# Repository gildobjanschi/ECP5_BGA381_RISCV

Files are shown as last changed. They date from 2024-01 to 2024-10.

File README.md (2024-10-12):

# Blue Whale Hardware
ECP5 FPGA board for developing a RISCV processor.

## Software
The ECP5 FPGA board was developed to enable the development of a RISCV processor and allow for for an extension connector. See the [RISCV_PROCESSOR](https://github.com/gildobjanschi/RISCV_PROCESSOR) project for detailed explanation of the Verilog code developed for this board.

## Project Status
The HW has been fully verified as part of the [RISCV_PROCESSOR](https://github.com/gildobjanschi/RISCV_PROCESSOR) project. An [extension board](https://github.com/gildobjanschi/ECP5_BGA381_RISCV_EXT)  was developed to test the extension interface. 

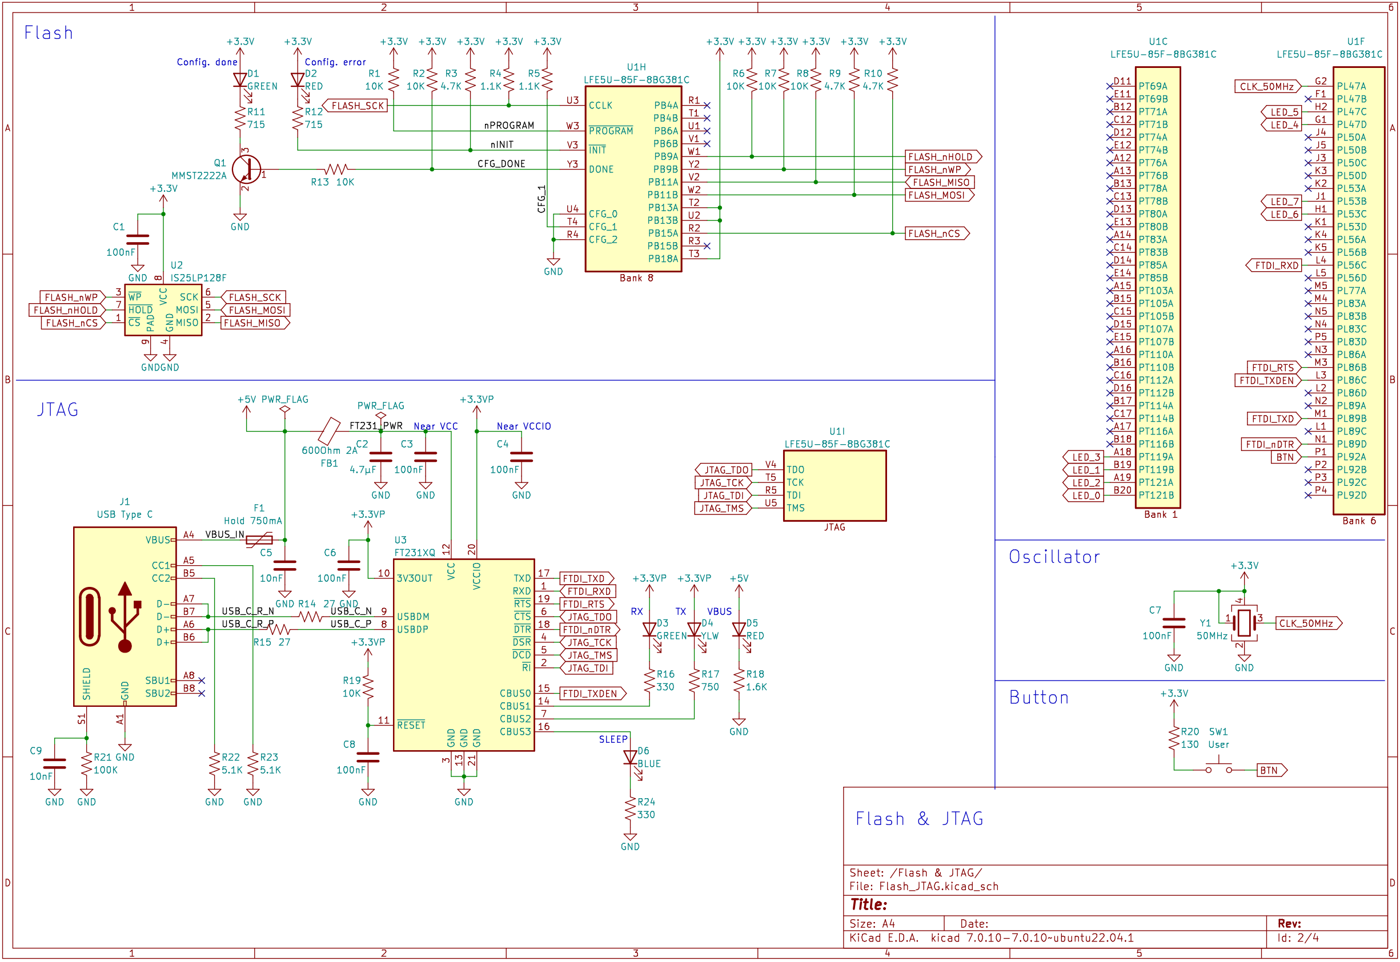
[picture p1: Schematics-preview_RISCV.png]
[](https://ECP5_BGA381_RISCV/blob/main/ECP5_board.pdf)

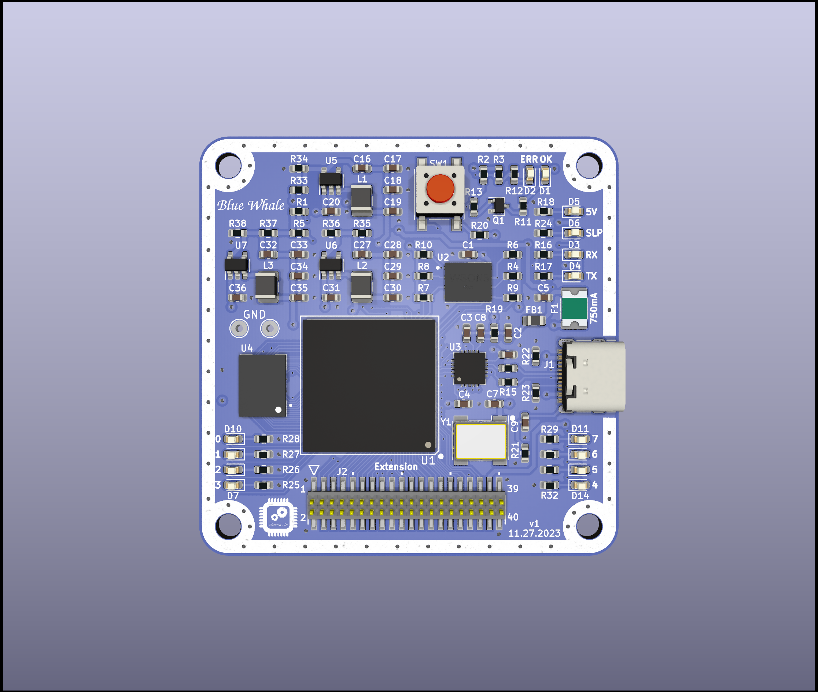
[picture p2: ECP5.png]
Blue Whale 3D view


## How To setup KiCAD
Checkout the KiCAD project and open it. In the Configure Paths dialog add: Name: ECP5_BGA381_RISCV and Path: "The full path to the GitHub directory"/GitHub/ECP5_BGA381_RISCV

In the Manage Symbol Libraries click the Project Specific Libraries tab and add: Name: ECP5_BGA381_RISCV and Library Path: ${ECP5_BGA381_RISCV}/symbols/Symbols.kicad_sym

In the Manage Footprint Libraries click the Project Specific Libraries tab and add: Name: ECP5_BGA381_RISCV and Library Path: ${ECP5_BGA381_RISCV}/footprints/Footprints.pretty

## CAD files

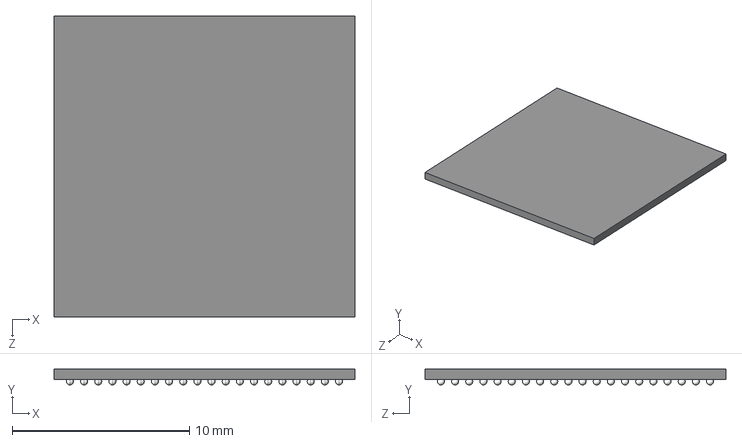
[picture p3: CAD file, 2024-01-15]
3dmodels/LFE5UM-85F-8BG381C.STEP
17.0 x 0.9 x 17.0 mm

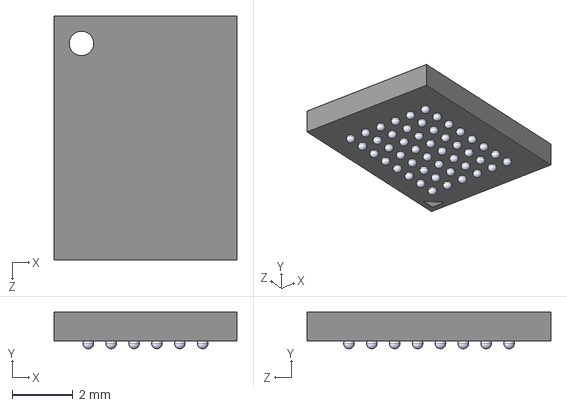
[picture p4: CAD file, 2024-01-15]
3dmodels/IS66WVE4M16EBLL-70BLI.STEP
6.00 x 1.20 x 8.00 mm

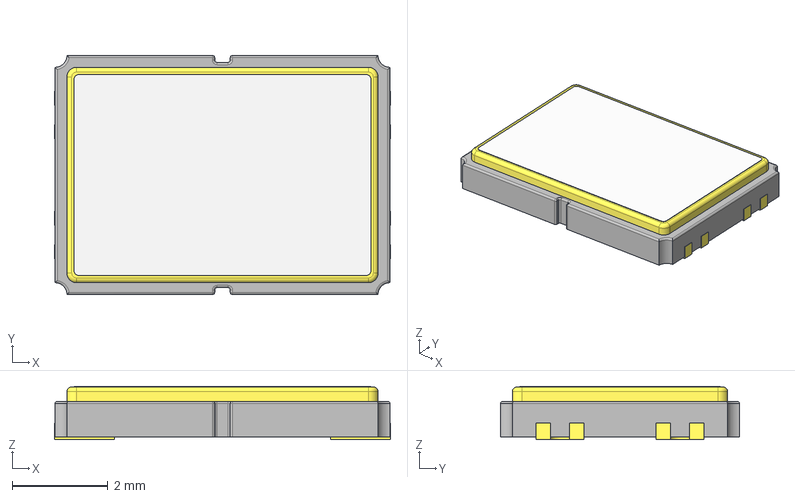
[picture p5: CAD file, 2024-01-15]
3dmodels/CRYSTAL_7050-4.step
7.02 x 5.00 x 1.11 mm
Pin
Pin001
Pin002
Pin003

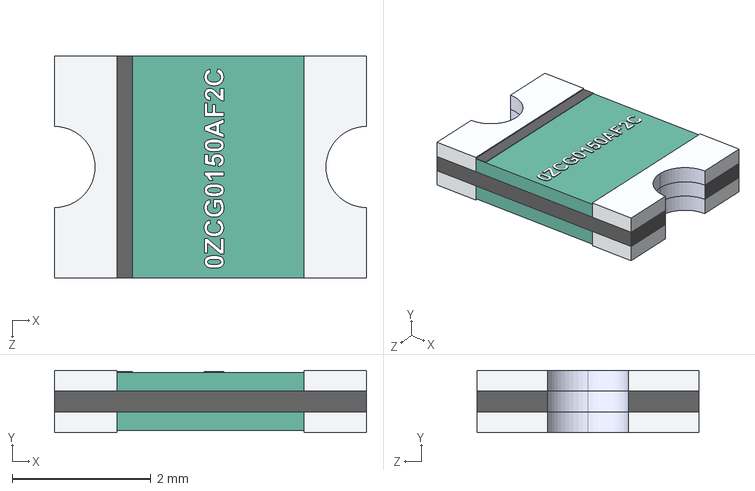
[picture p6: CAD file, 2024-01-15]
3dmodels/0ZCG-0_70mm.STEP
4.50 x 0.9 x 3.20 mm

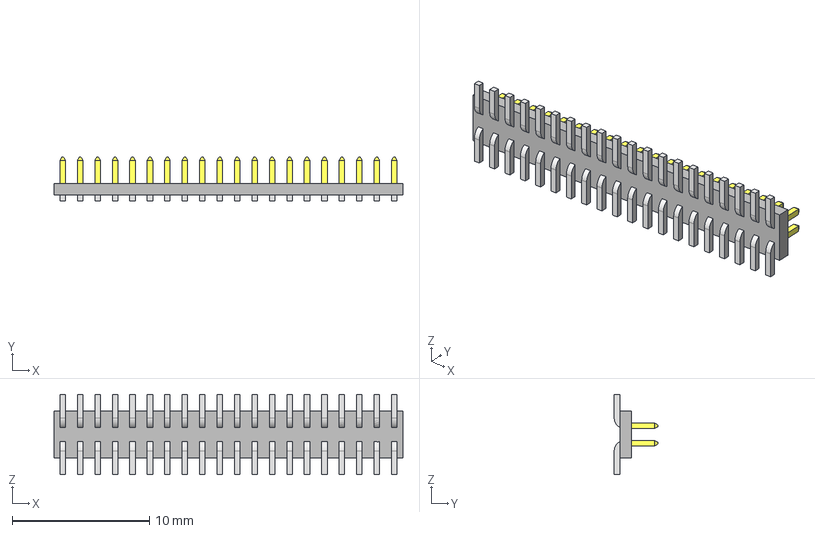
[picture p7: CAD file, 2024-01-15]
3dmodels/FTS-120-02-L-DV.stp
25.4 x 3.18 x 5.84 mm
FTS-120-02-L-DV_pins2
FTS-120-02-L-DV_pins1
FTS-120-02-L-DV_body

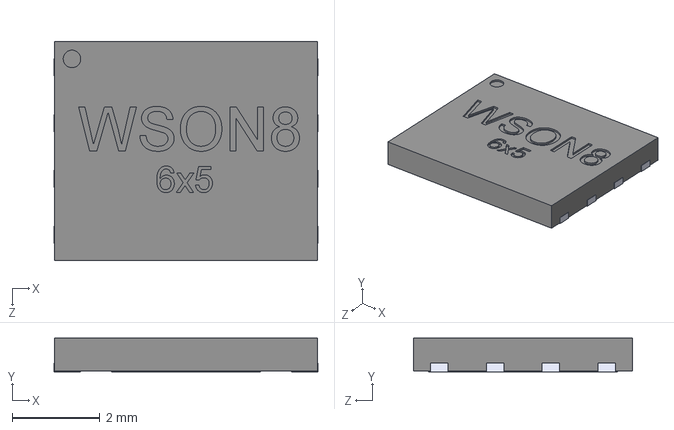
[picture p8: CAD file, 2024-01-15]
3dmodels/WSON8-6x5.STEP
6.02 x 0.77 x 5.00 mm

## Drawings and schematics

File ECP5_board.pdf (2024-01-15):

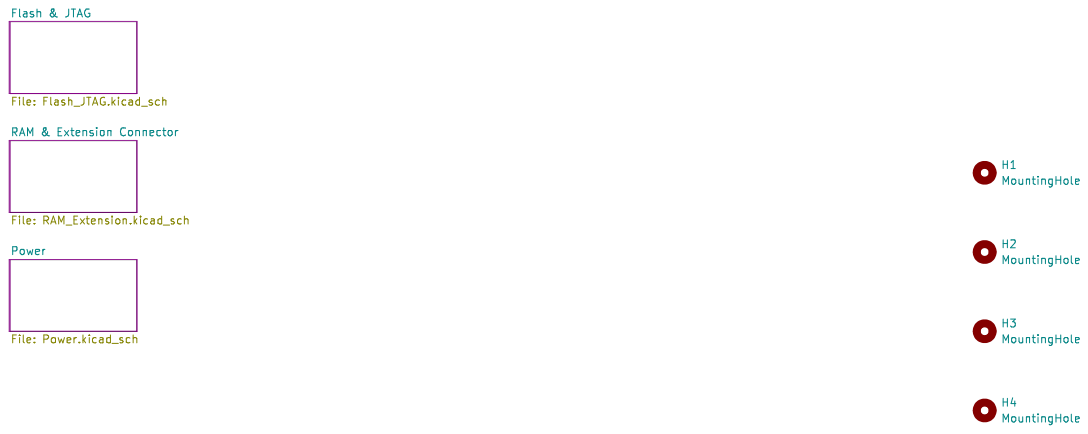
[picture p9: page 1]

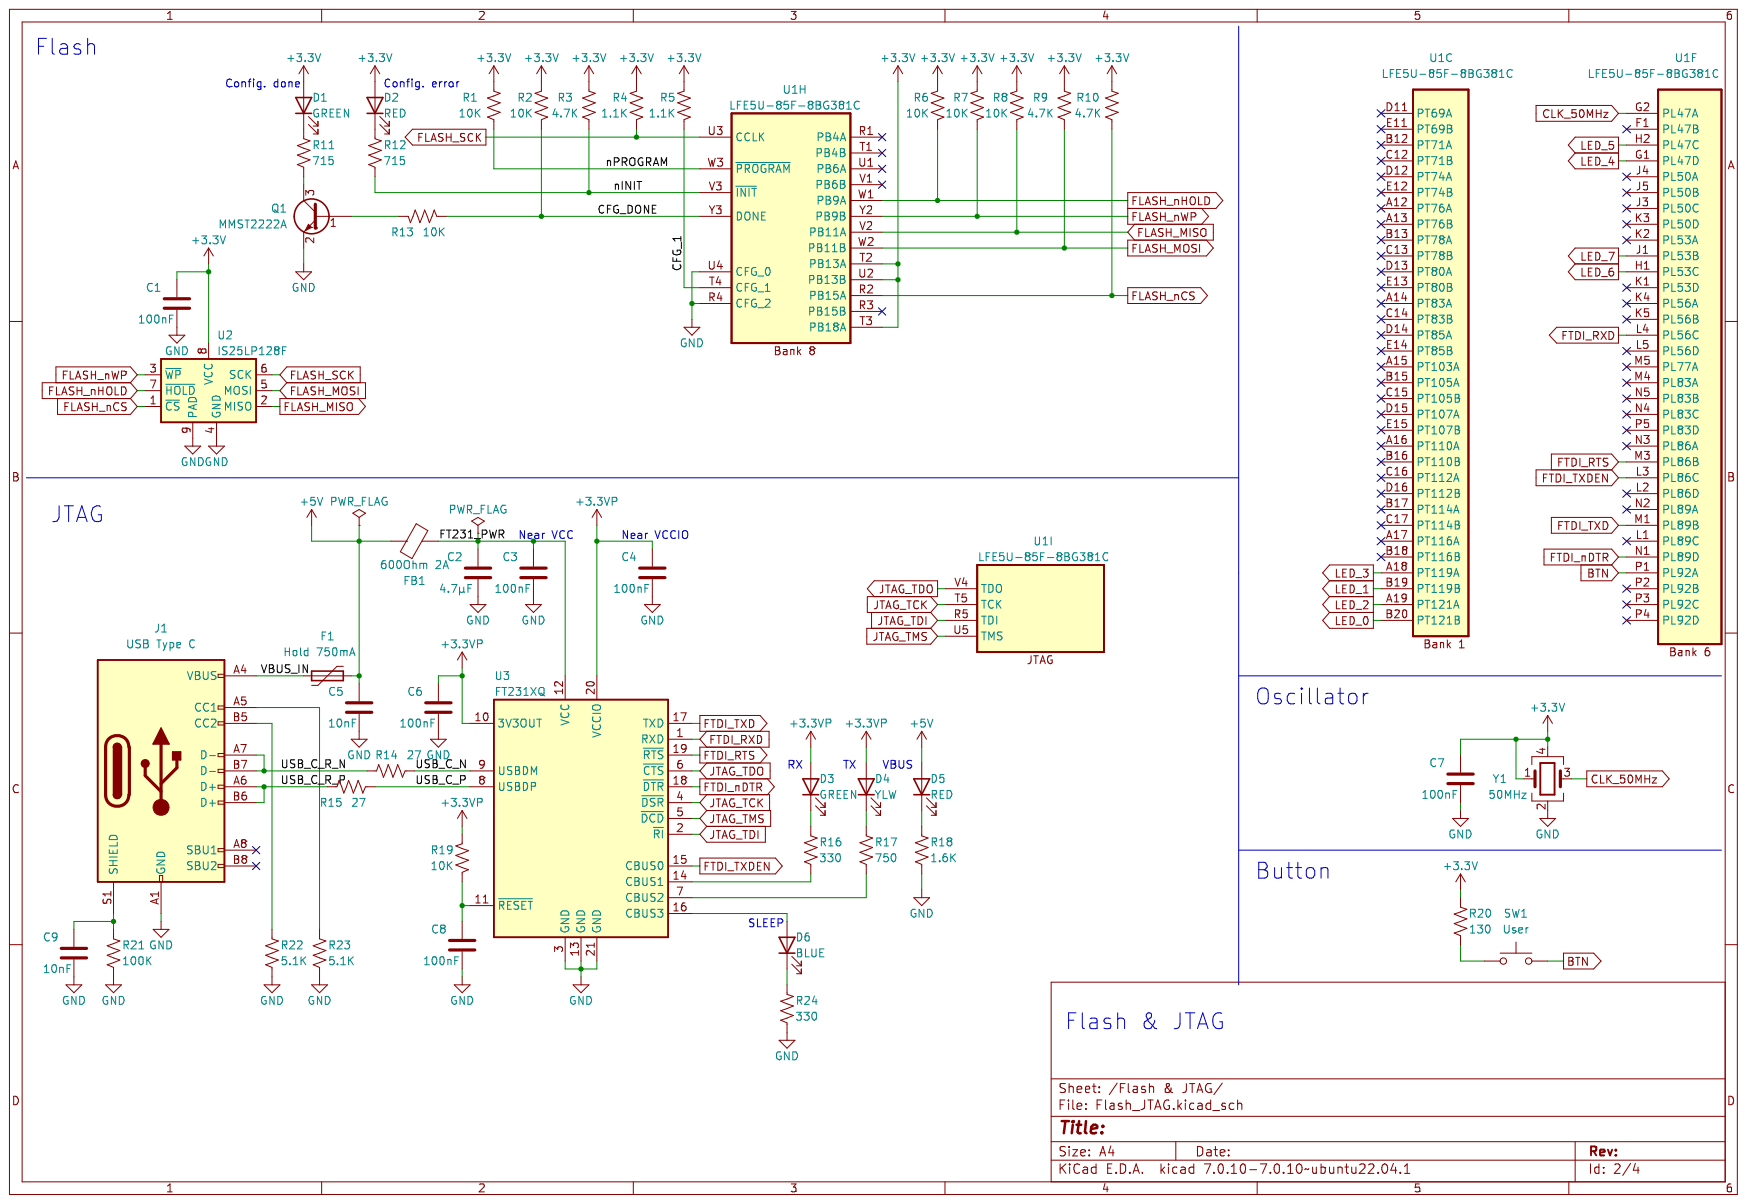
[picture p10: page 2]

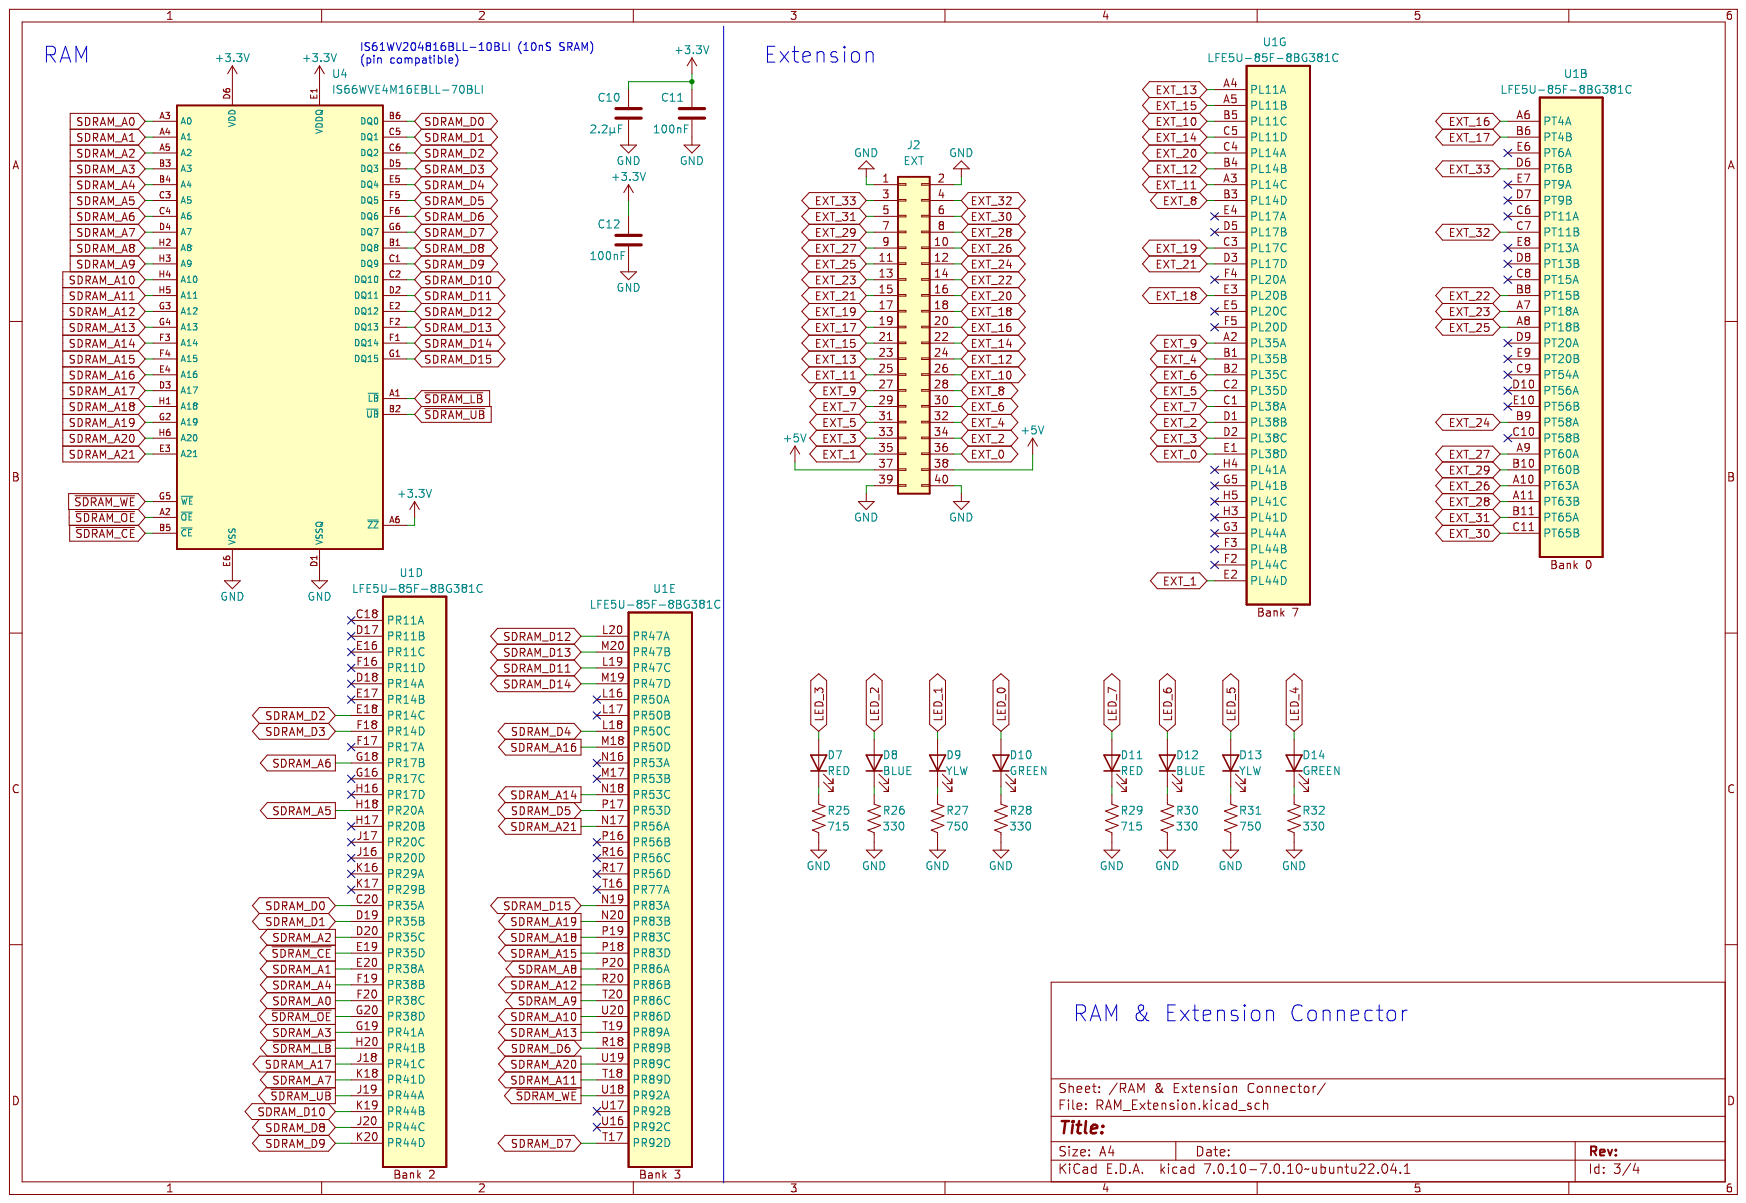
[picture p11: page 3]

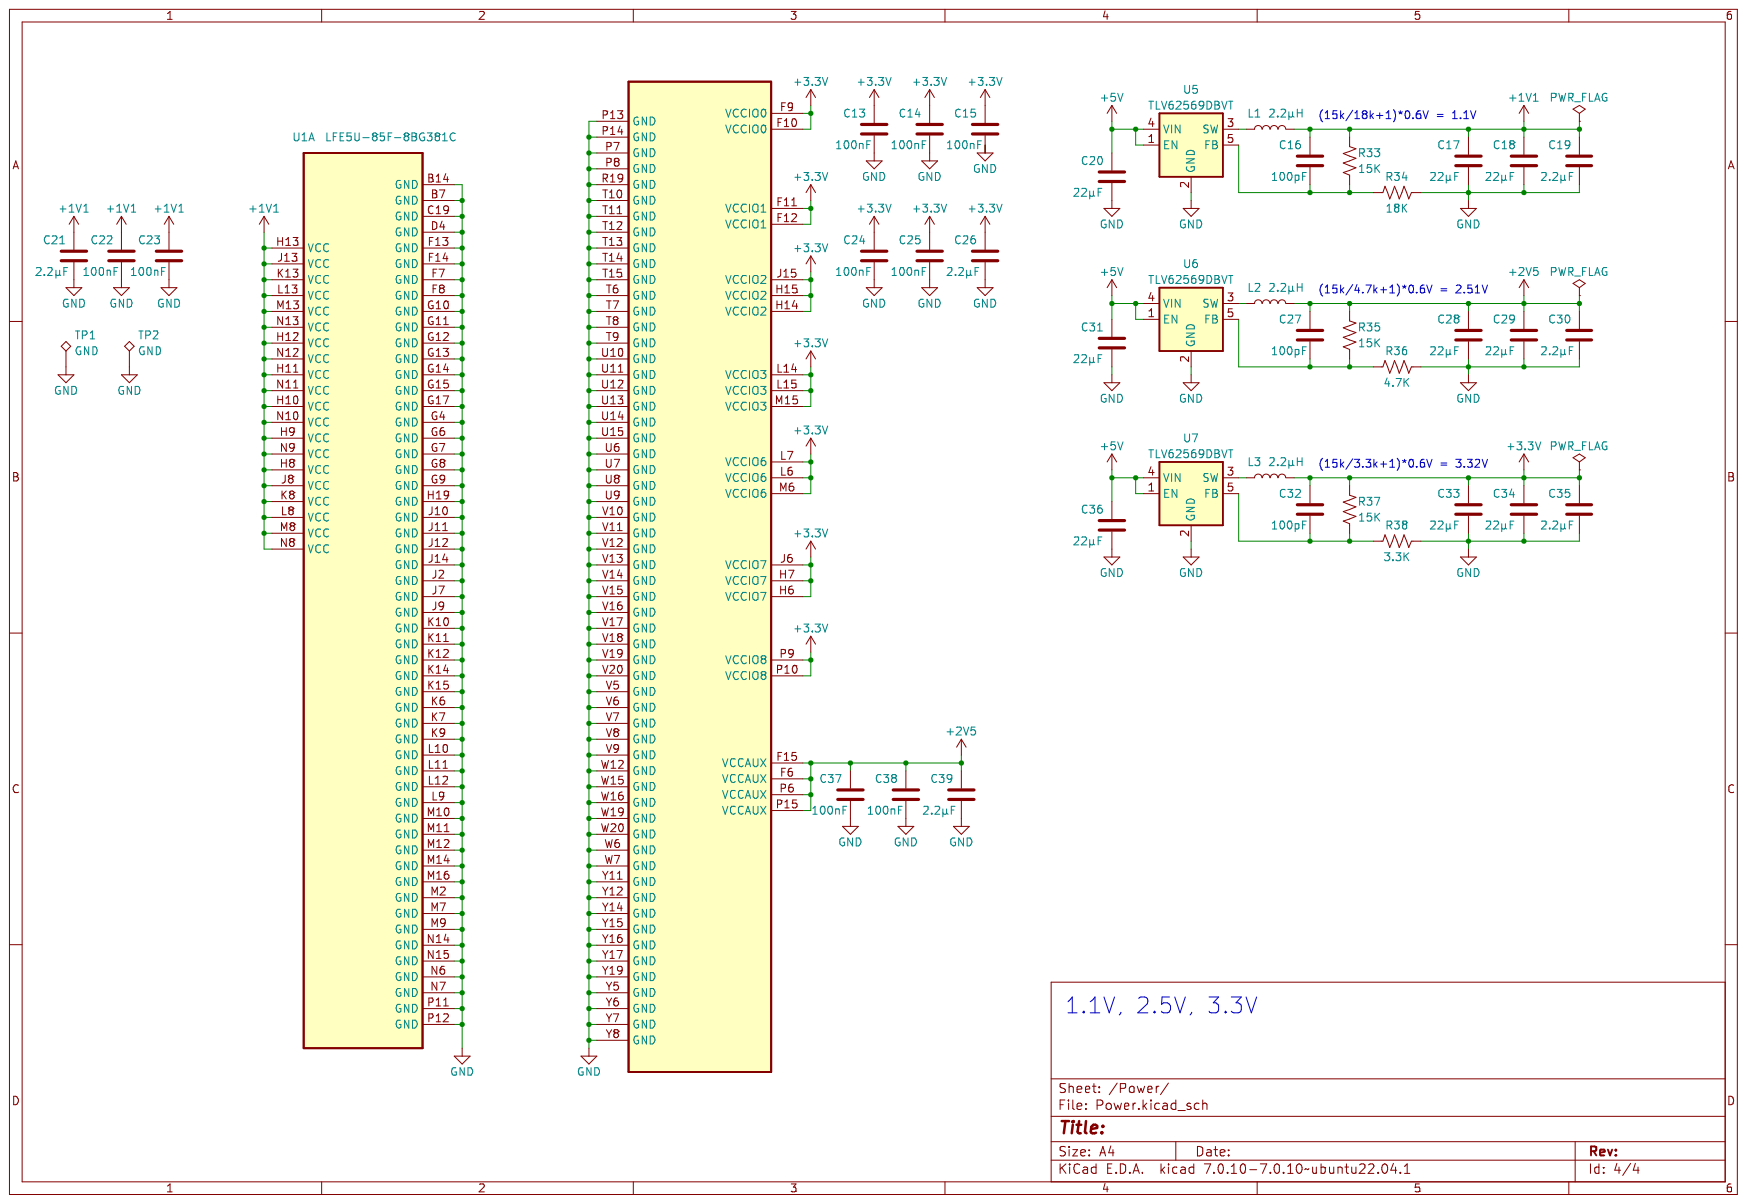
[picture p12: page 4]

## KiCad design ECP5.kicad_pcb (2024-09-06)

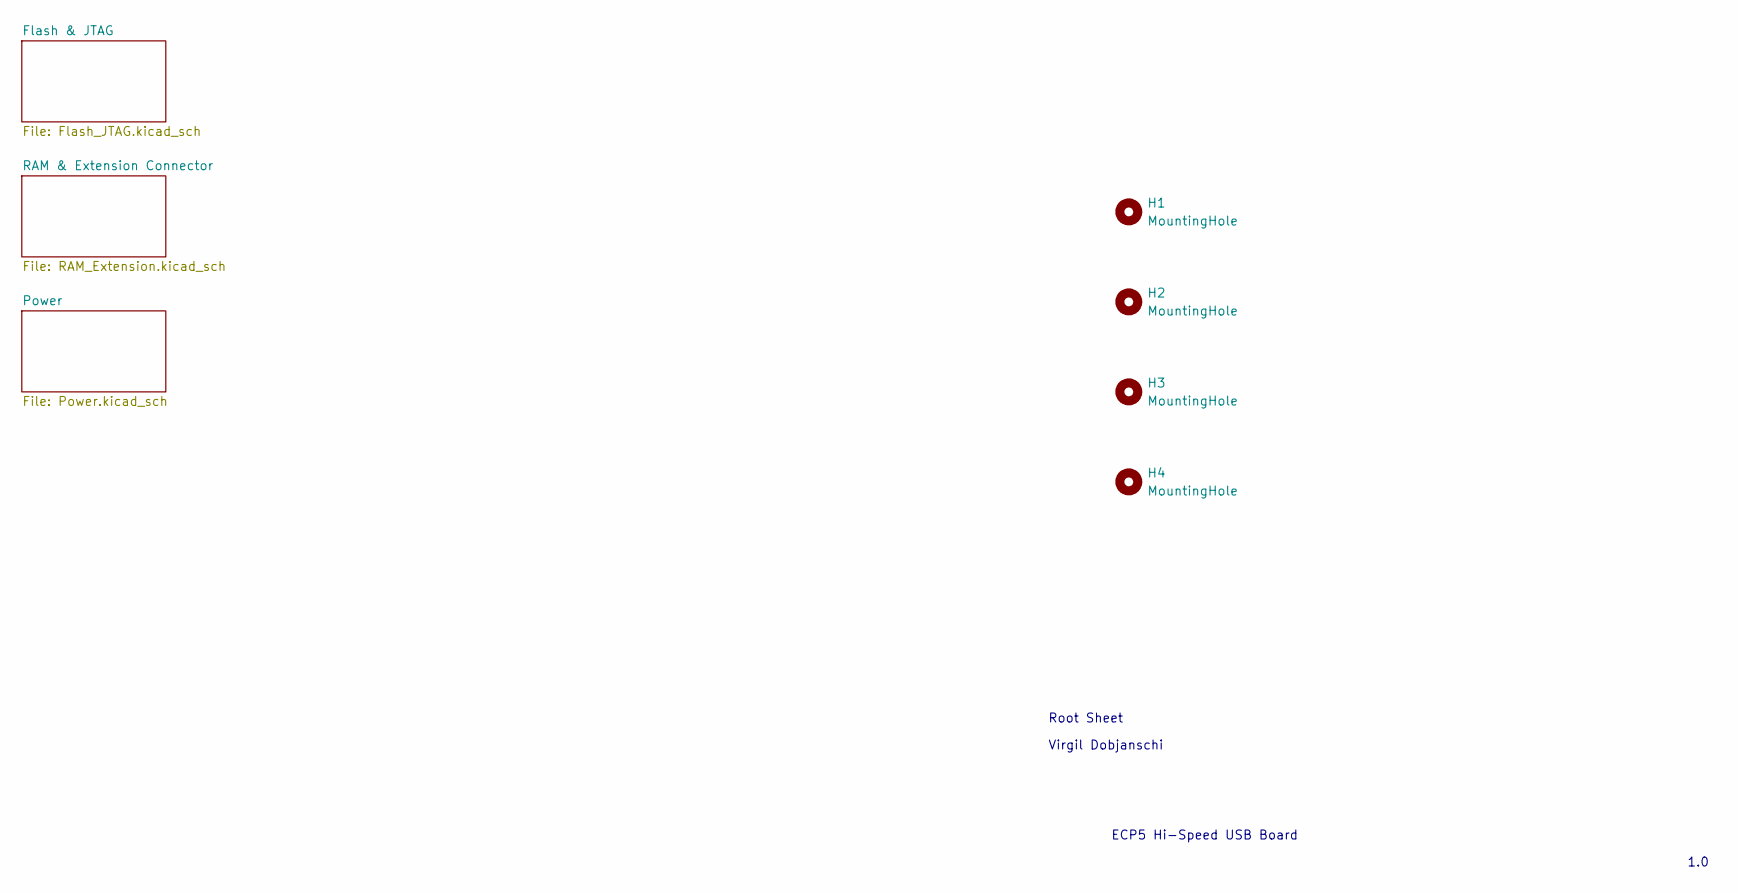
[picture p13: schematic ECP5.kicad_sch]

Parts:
H1, H2, H3, H4: MountingHole; MountingHole_3.2mm_M3

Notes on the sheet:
ECP5 Hi-Speed USB Board
Root Sheet
Virgil Dobjanschi
1.0

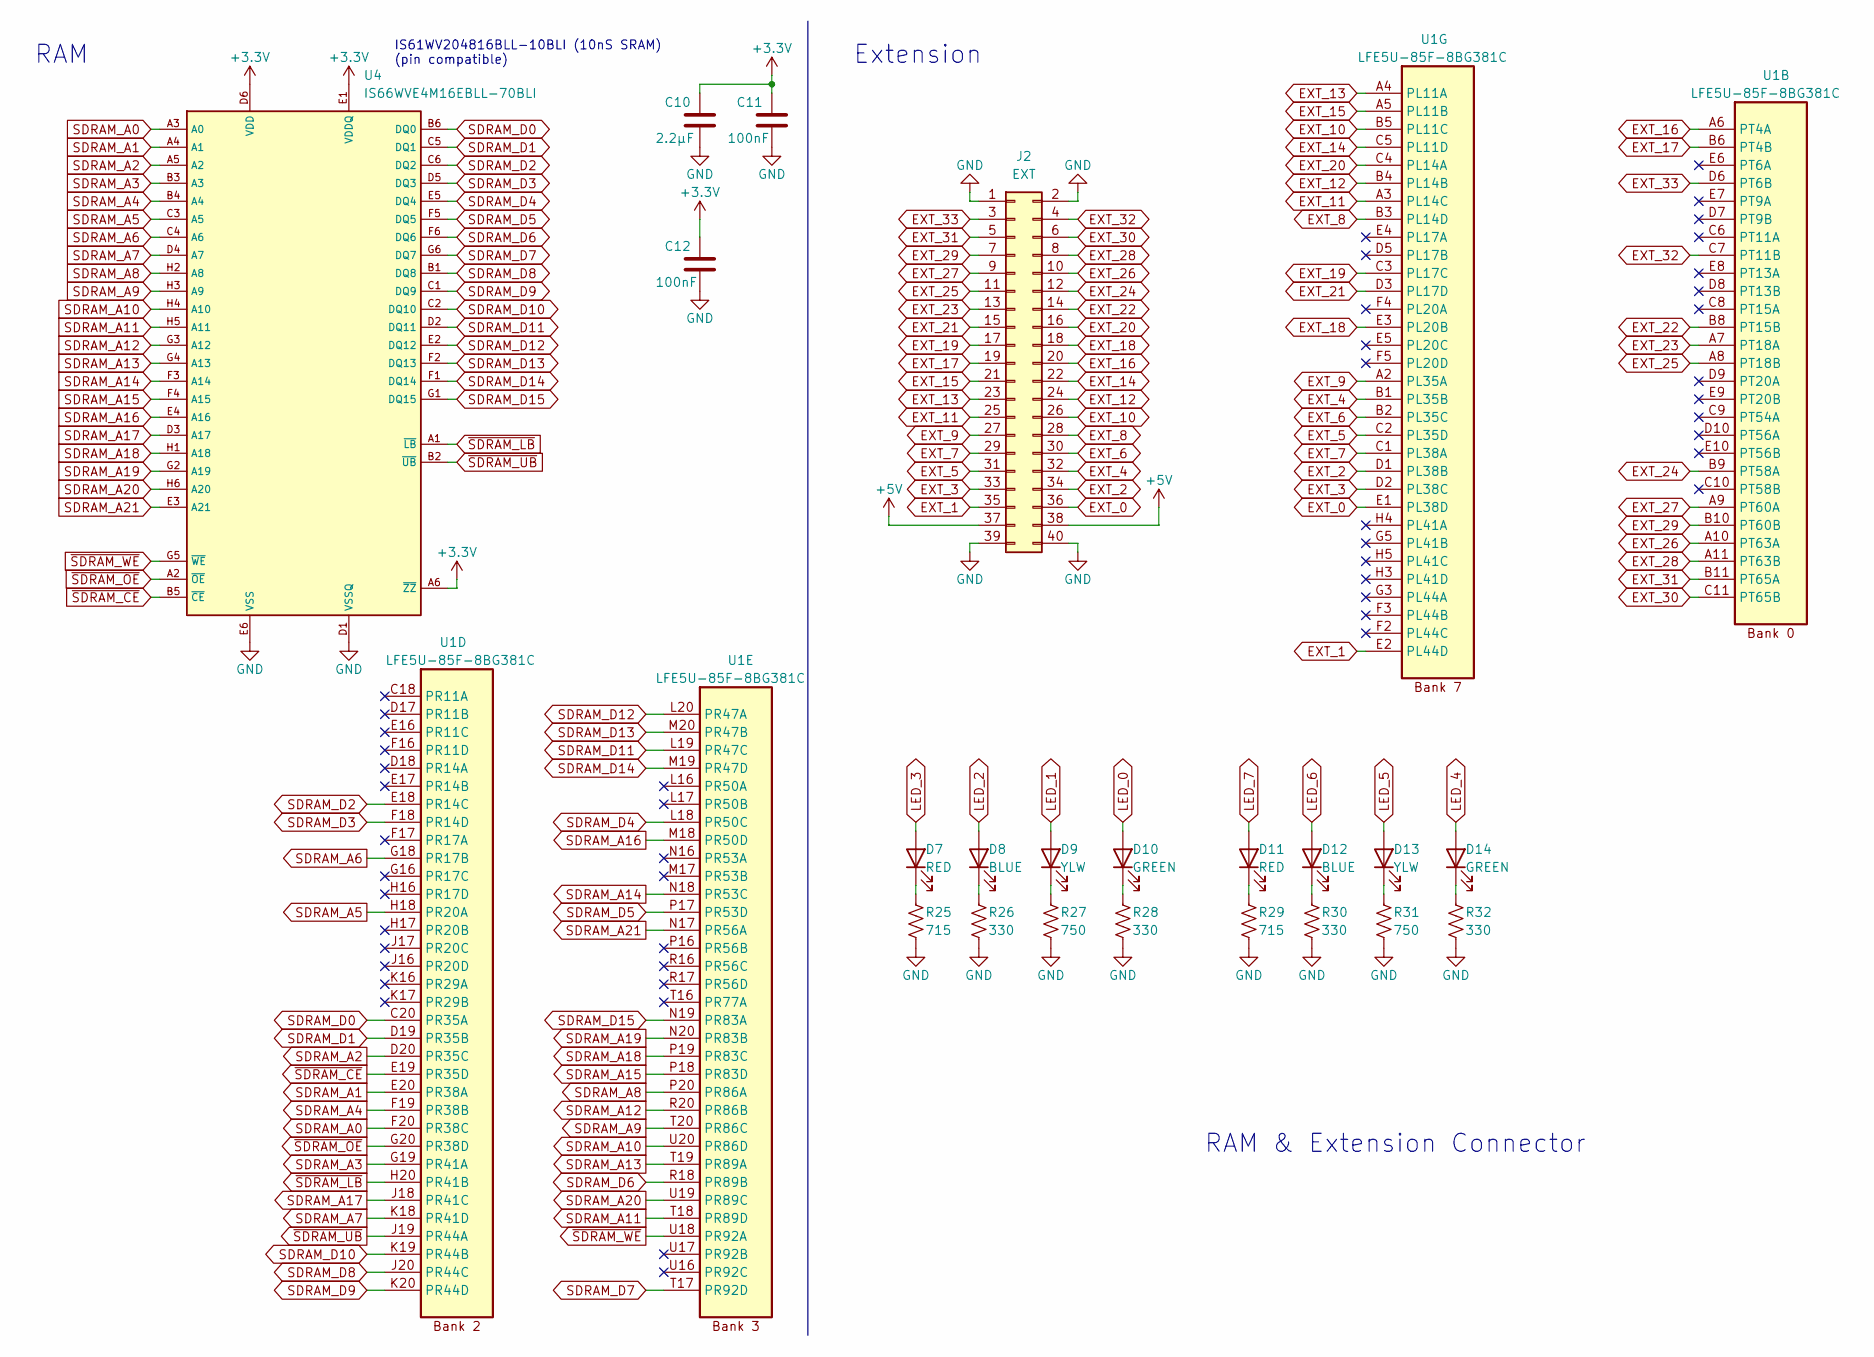
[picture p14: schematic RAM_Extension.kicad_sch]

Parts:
C10: 2.2µF; C_0603_1608Metric; MPN CL10B225KP8NNNC
C11, C12: 100nF; C_0603_1608Metric; MPN CL10B104KB8NNWC
D7, D11: RED; LED_0603_1608Metric; MPN APTD1608LSURCK
D8, D12: BLUE; LED_0603_1608Metric; MPN APTD1608LVBC/D
D9, D13: YLW; LED_0603_1608Metric; MPN APTD1608LSYCK/J3-PF
D10, D14: GREEN; LED_0603_1608Metric; MPN APTD1608LZGCK
J2: EXT; FTS-120-02-L-DV; MPN FTS-120-02-L-DV
R25, R29: 715; R_0603_1608Metric; MPN ERJ-3EKF7150V
R26, R28, R30, R32: 330; R_0603_1608Metric; MPN ERJ-3EKF3300V
R27, R31: 750; R_0603_1608Metric; MPN ERJ-3EKF7500V
U1: LFE5U-85F-8BG381C; BGA-381_pitch0.8mm_dia0.4mm; MPN LFE5U-85F-8BG381C
U4: IS66WVE4M16EBLL-70BLI; BGA48C75P8X6_800X600X120N; MPN IS66WVE4M16EBLL-70BLI

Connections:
+3.3V: C10.1, C11.1, C12.1, U4.A6 (~ZZ), U4.D6 (VDD), U4.E1 (VDDQ); also elsewhere on the board
+5V: J2.37, J2.38; also elsewhere on the board
EXT_0: J2.36, U1.E1 (PL38D)
EXT_1: J2.35, U1.E2 (PL44D)
EXT_2: J2.34, U1.D1 (PL38B)
EXT_3: J2.33, U1.D2 (PL38C)
EXT_4: J2.32, U1.B1 (PL35B)
EXT_5: J2.31, U1.C2 (PL35D)
EXT_6: J2.30, U1.B2 (PL35C)
EXT_7: J2.29, U1.C1 (PL38A)
EXT_8: J2.28, U1.B3 (PL14D)
EXT_9: J2.27, U1.A2 (PL35A)
EXT_10: J2.26, U1.B5 (PL11C)
EXT_11: J2.25, U1.A3 (PL14C)
EXT_12: J2.24, U1.B4 (PL14B)
EXT_13: J2.23, U1.A4 (PL11A)
EXT_14: J2.22, U1.C5 (PL11D)
EXT_15: J2.21, U1.A5 (PL11B)
EXT_16: J2.20, U1.A6 (PT4A)
EXT_17: J2.19, U1.B6 (PT4B)
EXT_18: J2.18, U1.E3 (PL20B)
EXT_19: J2.17, U1.C3 (PL17C)
EXT_20: J2.16, U1.C4 (PL14A)
EXT_21: J2.15, U1.D3 (PL17D)
EXT_22: J2.14, U1.B8 (PT15B)
EXT_23: J2.13, U1.A7 (PT18A)
EXT_24: J2.12, U1.B9 (PT58A)
EXT_25: J2.11, U1.A8 (PT18B)
EXT_26: J2.10, U1.A10 (PT63A)
EXT_27: J2.9, U1.A9 (PT60A)
EXT_28: J2.8, U1.A11 (PT63B)
EXT_29: J2.7, U1.B10 (PT60B)
EXT_30: J2.6, U1.C11 (PT65B)
EXT_31: J2.5, U1.B11 (PT65A)
EXT_32: J2.4, U1.C7 (PT11B)
EXT_33: J2.3, U1.D6 (PT6B)
GND: C10.2, C11.2, C12.2, J2.1, J2.2, J2.39, J2.40, R25.2, R26.2, R27.2, R28.2, R29.2, R30.2, R31.2, R32.2, U4.D1 (VSSQ), U4.E6 (VSS); also elsewhere on the board
LED_0: D10.2 (A); also elsewhere on the board
LED_1: D9.2 (A); also elsewhere on the board
LED_2: D8.2 (A); also elsewhere on the board
LED_3: D7.2 (A); also elsewhere on the board
LED_4: D14.2 (A); also elsewhere on the board
LED_5: D13.2 (A); also elsewhere on the board
LED_6: D12.2 (A); also elsewhere on the board
LED_7: D11.2 (A); also elsewhere on the board
unnamed: D7.1 (K), R25.1
unnamed: D8.1 (K), R26.1
unnamed: D9.1 (K), R27.1
unnamed: D10.1 (K), R28.1
unnamed: D11.1 (K), R29.1
unnamed: D12.1 (K), R30.1
unnamed: D13.1 (K), R31.1
unnamed: D14.1 (K), R32.1
SDRAM_A0: U1.F20 (PR38C), U4.A3 (A0)
SDRAM_A1: U1.E20 (PR38A), U4.A4 (A1)
SDRAM_A2: U1.D20 (PR35C), U4.A5 (A2)
SDRAM_A3: U1.G19 (PR41A), U4.B3 (A3)
SDRAM_A4: U1.F19 (PR38B), U4.B4 (A4)
SDRAM_A5: U1.H18 (PR20A), U4.C3 (A5)
SDRAM_A6: U1.G18 (PR17B), U4.C4 (A6)
SDRAM_A7: U1.K18 (PR41D), U4.D4 (A7)
SDRAM_A8: U1.P20 (PR86A), U4.H2 (A8)
SDRAM_A9: U1.T20 (PR86C), U4.H3 (A9)
SDRAM_A10: U1.U20 (PR86D), U4.H4 (A10)
SDRAM_A11: U1.T18 (PR89D), U4.H5 (A11)
SDRAM_A12: U1.R20 (PR86B), U4.G3 (A12)
SDRAM_A13: U1.T19 (PR89A), U4.G4 (A13)
SDRAM_A14: U1.N18 (PR53C), U4.F3 (A14)
SDRAM_A15: U1.P18 (PR83D), U4.F4 (A15)
SDRAM_A16: U1.M18 (PR50D), U4.E4 (A16)
SDRAM_A17: U1.J18 (PR41C), U4.D3 (A17)
SDRAM_A18: U1.P19 (PR83C), U4.H1 (A18)
SDRAM_A19: U1.N20 (PR83B), U4.G2 (A19)
SDRAM_A20: U1.U19 (PR89C), U4.H6 (A20)
SDRAM_A21: U1.N17 (PR56A), U4.E3 (A21)
SDRAM_D0: U1.C20 (PR35A), U4.B6 (DQ0)
SDRAM_D1: U1.D19 (PR35B), U4.C5 (DQ1)
SDRAM_D2: U1.E18 (PR14C), U4.C6 (DQ2)
SDRAM_D3: U1.F18 (PR14D), U4.D5 (DQ3)
SDRAM_D4: U1.L18 (PR50C), U4.E5 (DQ4)
SDRAM_D5: U1.P17 (PR53D), U4.F5 (DQ5)
SDRAM_D6: U1.R18 (PR89B), U4.F6 (DQ6)
SDRAM_D7: U1.T17 (PR92D), U4.G6 (DQ7)
SDRAM_D8: U1.J20 (PR44C), U4.B1 (DQ8)
SDRAM_D9: U1.K20 (PR44D), U4.C1 (DQ9)
SDRAM_D10: U1.K19 (PR44B), U4.C2 (DQ10)
SDRAM_D11: U1.L19 (PR47C), U4.D2 (DQ11)
SDRAM_D12: U1.L20 (PR47A), U4.E2 (DQ12)
SDRAM_D13: U1.M20 (PR47B), U4.F2 (DQ13)
SDRAM_D14: U1.M19 (PR47D), U4.F1 (DQ14)
SDRAM_D15: U1.N19 (PR83A), U4.G1 (DQ15)
~SDRAM_CE: U1.E19 (PR35D), U4.B5 (~CE)
~SDRAM_LB: U1.H20 (PR41B), U4.A1 (~LB)
~SDRAM_OE: U1.G20 (PR38D), U4.A2 (~OE)
~SDRAM_UB: U1.J19 (PR44A), U4.B2 (~UB)
~SDRAM_WE: U1.U18 (PR92A), U4.G5 (~WE)

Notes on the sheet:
RAM
Extension
IS61WV204816BLL-10BLI (10nS SRAM) (pin compatible)
RAM & Extension Connector

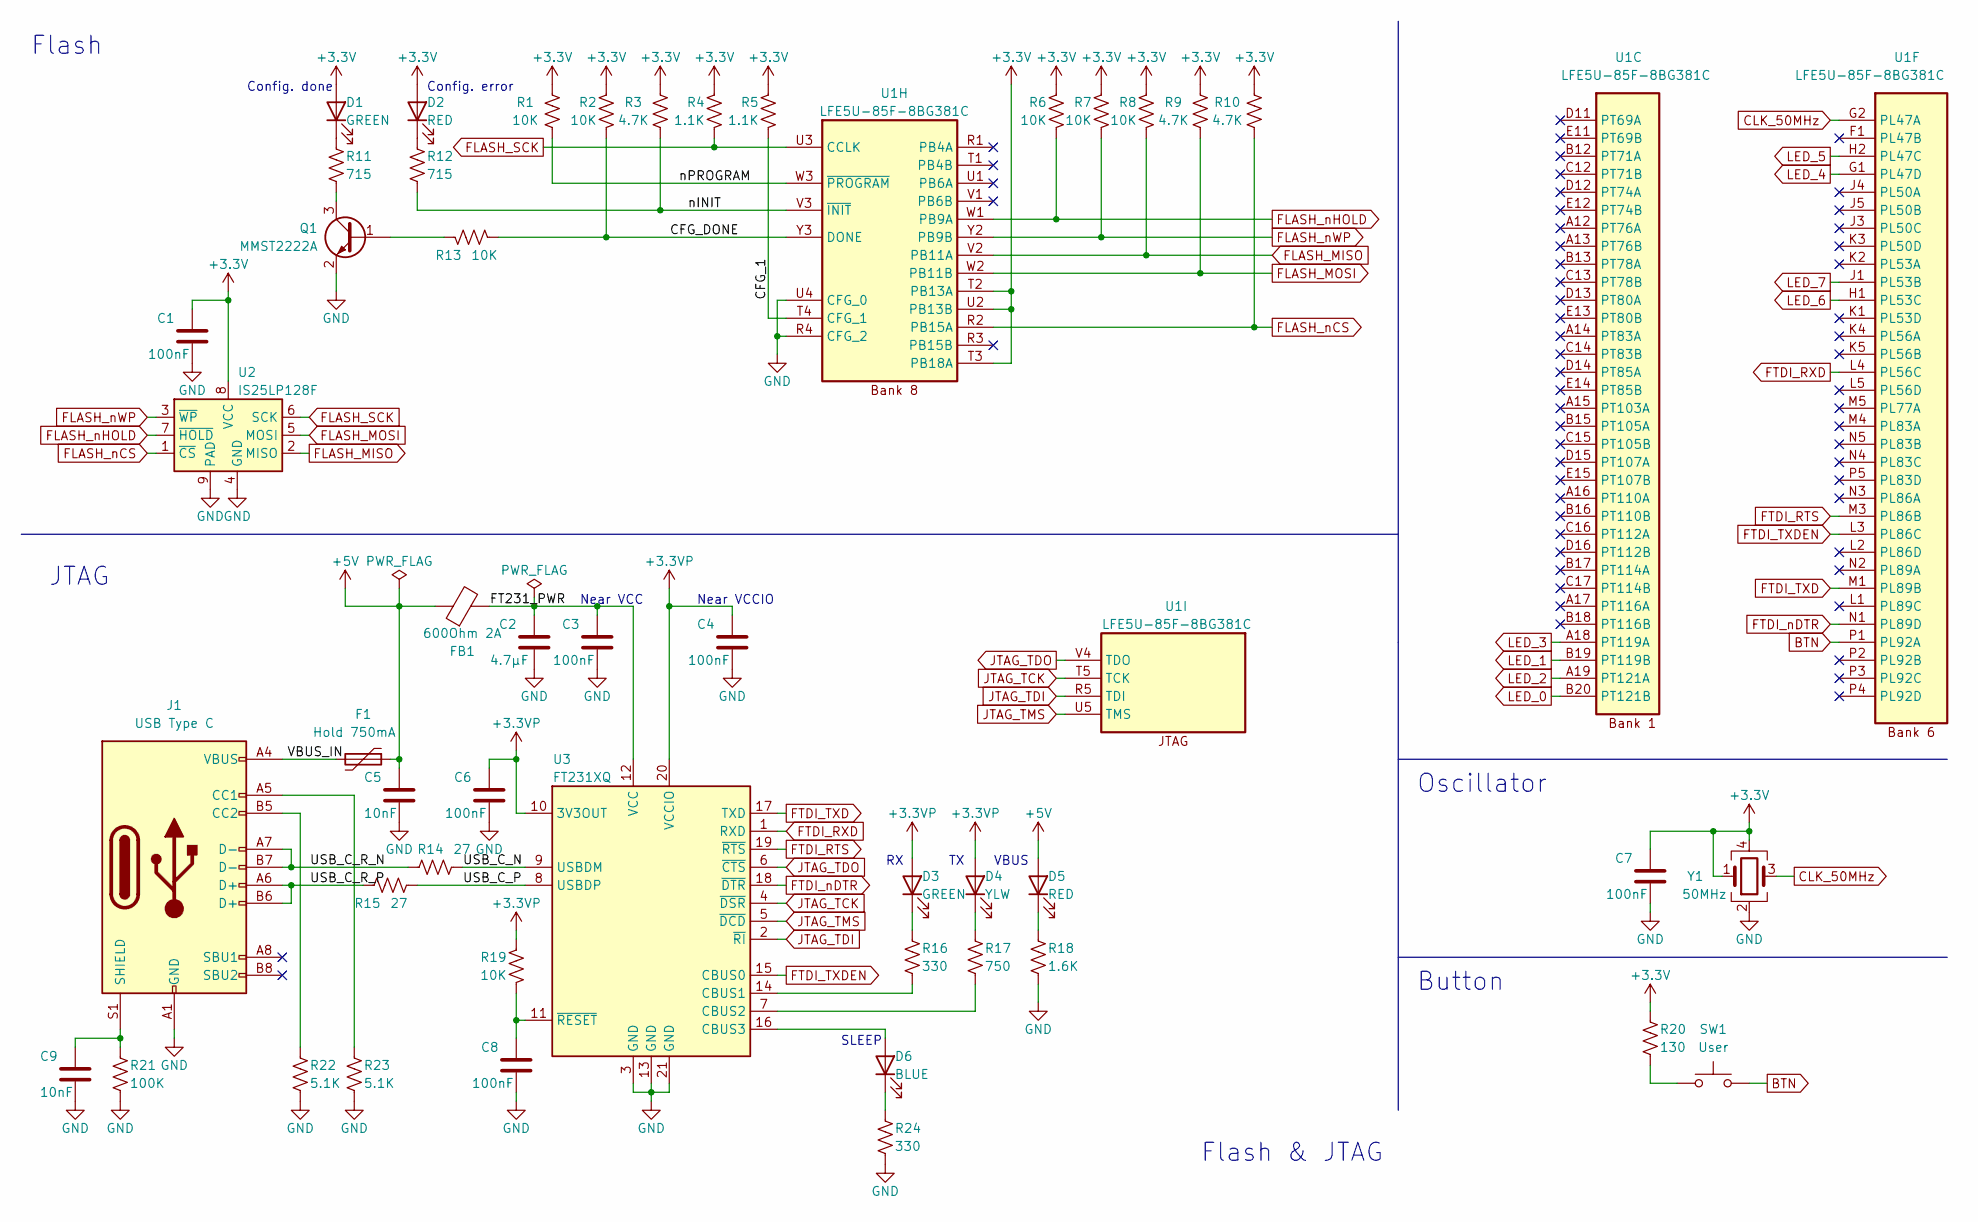
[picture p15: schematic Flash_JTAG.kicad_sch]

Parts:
C1, C3, C4, C6, C7, C8: 100nF; C_0603_1608Metric; MPN CL10B104KB8NNWC
C2: 4.7µF; C_0603_1608Metric; MPN CL10A475KP8NNNC
C5, C9: 10nF; C_0603_1608Metric; MPN CL10B103KB8NNWC
D1, D3: GREEN; LED_0603_1608Metric; MPN APTD1608LZGCK
D2, D5: RED; LED_0603_1608Metric; MPN APTD1608LSURCK
D4: YLW; LED_0603_1608Metric; MPN APTD1608LSYCK/J3-PF
D6: BLUE; LED_0603_1608Metric; MPN APTD1608LVBC/D
F1: Hold 750mA; Fuse_1812_4532Metric; MPN 0ZCG0075FF2C
FB1: 600Ohm 2A; L_0805_2012Metric; MPN 78279220601
J1: USB Type C; USB_C_Receptacle_GCT_USB4105-xx-A_16P_TopMnt_Horizontal; MPN USB4105-GF-A-120
Q1: MMST2222A; SOT-323_SC-70; MPN MMST2222A-7-F
R1, R2, R6, R7, R8, R13, R19: 10K; R_0603_1608Metric; MPN ERJ-3EKF1002V
R3, R9, R10: 4.7K; R_0603_1608Metric; MPN ERJ-3EKF4701V
R4, R5: 1.1K; R_0603_1608Metric; MPN ERJ-3EKF1101V
R11, R12: 715; R_0603_1608Metric; MPN ERJ-3EKF7150V
R14, R15: 27; R_0603_1608Metric; MPN ERJ-3EKF27R0V
R16, R24: 330; R_0603_1608Metric; MPN ERJ-3EKF3300V
R17: 750; R_0603_1608Metric; MPN ERJ-3EKF7500V
R18: 1.6K; R_0603_1608Metric; MPN ERJ-3EKF1601V
R20: 130; R_0603_1608Metric; MPN ERJ-3EKF1300V
R21: 100K; R_0603_1608Metric; MPN ERJ-3EKF1003V
R22, R23: 5.1K; R_0603_1608Metric; MPN ERJ-3EKF5101V
SW1: User; SW_SPST_PTS645; MPN PTS645SK43SMTR92 LFS
U1: LFE5U-85F-8BG381C; BGA-381_pitch0.8mm_dia0.4mm; MPN LFE5U-85F-8BG381C
U2: IS25LP128F; WSON-8-1EP_6x5mm_P1.27mm_EP3.4x4.3mm; MPN IS25LP128-JKLE
U3: FT231XQ; QFN-20-1EP_4x4mm_P0.5mm_EP2.5x2.5mm; MPN FT231XQ-R
Y1: 50MHz; Oscillator_SMD_Diodes_FN-4Pin_7.0x5.0mm; MPN ECS-7050MV-500-DM-TR

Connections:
+3.3V: C1.1, C7.1, D1.2 (A), D2.2 (A), R1.2, R2.1, R3.2, R4.1, R5.1, R6.1, R7.1, R8.1, R9.2, R10.2, R20.1, U1.T2 (PB13A), U1.T3 (PB18A), U1.U2 (PB13B), U2.8 (VCC), Y1.1, Y1.4; also elsewhere on the board
+3.3VP: C4.1, C6.1, D3.2 (A), D4.2 (A), R19.1, U3.10 (3V3OUT), U3.20 (VCCIO)
+5V: C5.1, D5.2 (A), F1.1, FB1.1; also elsewhere on the board
/Flash & JTAG/CFG_1: R5.2, U1.T4 (CFG_1)
/Flash & JTAG/CFG_DONE: R2.2, R13.2, U1.Y3 (DONE)
/Flash & JTAG/FT231_PWR: C2.1, C3.1, FB1.2, U3.12 (VCC)
/Flash & JTAG/USB_C_N: R14.2, U3.9 (USBDM)
/Flash & JTAG/USB_C_P: R15.2, U3.8 (USBDP)
/Flash & JTAG/USB_C_R_N: J1.A7 (D-), J1.B7 (D-), R14.1
/Flash & JTAG/USB_C_R_P: J1.A6 (D+), J1.B6 (D+), R15.1
/Flash & JTAG/VBUS_IN: F1.2, J1.A4 (VBUS), J1.A9 (VBUS), J1.B4 (VBUS), J1.B9 (VBUS)
/Flash & JTAG/nINIT: R3.1, R12.2, U1.V3 (~INIT)
/Flash & JTAG/nPROGRAM: R1.1, U1.W3 (~PROGRAM)
BTN: SW1.2, U1.P1 (PL92A)
CLK_50MHz: U1.G2 (PL47A), Y1.3
FLASH_MISO: R8.2, U1.V2 (PB11A), U2.2 (MISO)
FLASH_MOSI: R9.1, U1.W2 (PB11B), U2.5 (MOSI)
FLASH_SCK: R4.2, U1.U3 (CCLK), U2.6 (SCK)
FLASH_nCS: R10.1, U1.R2 (PB15A), U2.1 (~CS)
FLASH_nHOLD: R6.2, U1.W1 (PB9A), U2.7 (~HOLD)
FLASH_nWP: R7.2, U1.Y2 (PB9B), U2.3 (~WP)
FTDI_RTS: U1.M3 (PL86B), U3.19 (~RTS)
FTDI_RXD: U1.L4 (PL56C), U3.1 (RXD)
FTDI_TXD: U1.M1 (PL89B), U3.17 (TXD)
FTDI_TXDEN: U1.L3 (PL86C), U3.15 (CBUS0)
FTDI_nDTR: U1.N1 (PL89D), U3.18 (~DTR)
GND: C1.2, C2.2, C3.2, C4.2, C5.2, C6.2, C7.2, C8.2, C9.2, J1.A1 (GND), J1.A12 (GND), J1.B1 (GND), J1.B12 (GND), Q1.2 (E), R18.2, R21.2, R22.2, R23.2, R24.2, U1.R4 (CFG_2), U1.U4 (CFG_0), U2.4 (GND), U2.9 (PAD), U3.3 (GND), U3.13 (GND), U3.21 (GND), Y1.2; also elsewhere on the board
JTAG_TCK: U1.T5 (TCK), U3.4 (~DSR)
JTAG_TDI: U1.R5 (TDI), U3.2 (~RI)
JTAG_TDO: U1.V4 (TDO), U3.6 (~CTS)
JTAG_TMS: U1.U5 (TMS), U3.5 (~DCD)
LED_0: U1.B20 (PT121B); also elsewhere on the board
LED_1: U1.B19 (PT119B); also elsewhere on the board
LED_2: U1.A19 (PT121A); also elsewhere on the board
LED_3: U1.A18 (PT119A); also elsewhere on the board
LED_4: U1.G1 (PL47D); also elsewhere on the board
LED_5: U1.H2 (PL47C); also elsewhere on the board
LED_6: U1.H1 (PL53C); also elsewhere on the board
LED_7: U1.J1 (PL53B); also elsewhere on the board
unnamed: D1.1 (K), R11.1
unnamed: D2.1 (K), R12.1
unnamed: D3.1 (K), R16.1
unnamed: D4.1 (K), R17.1
unnamed: D5.1 (K), R18.1
unnamed: D6.2 (A), U3.16 (CBUS3)
unnamed: D6.1 (K), R24.1
unnamed: J1.A5 (CC1), R23.1
unnamed: J1.B5 (CC2), R22.1
unnamed: C9.1, J1.S1 (SHIELD), R21.1
unnamed: Q1.1 (B), R13.1
unnamed: Q1.3 (C), R11.2
unnamed: R20.2, SW1.1
unnamed: R16.2, U3.14 (CBUS1)
unnamed: R17.2, U3.7 (CBUS2)
unnamed: C8.1, R19.2, U3.11 (~RESET)

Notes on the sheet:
Near VCCIO
Flash
Near VCC
Flash & JTAG
SLEEP
Oscillator
Button
VBUS
Config. done
JTAG
Config. error

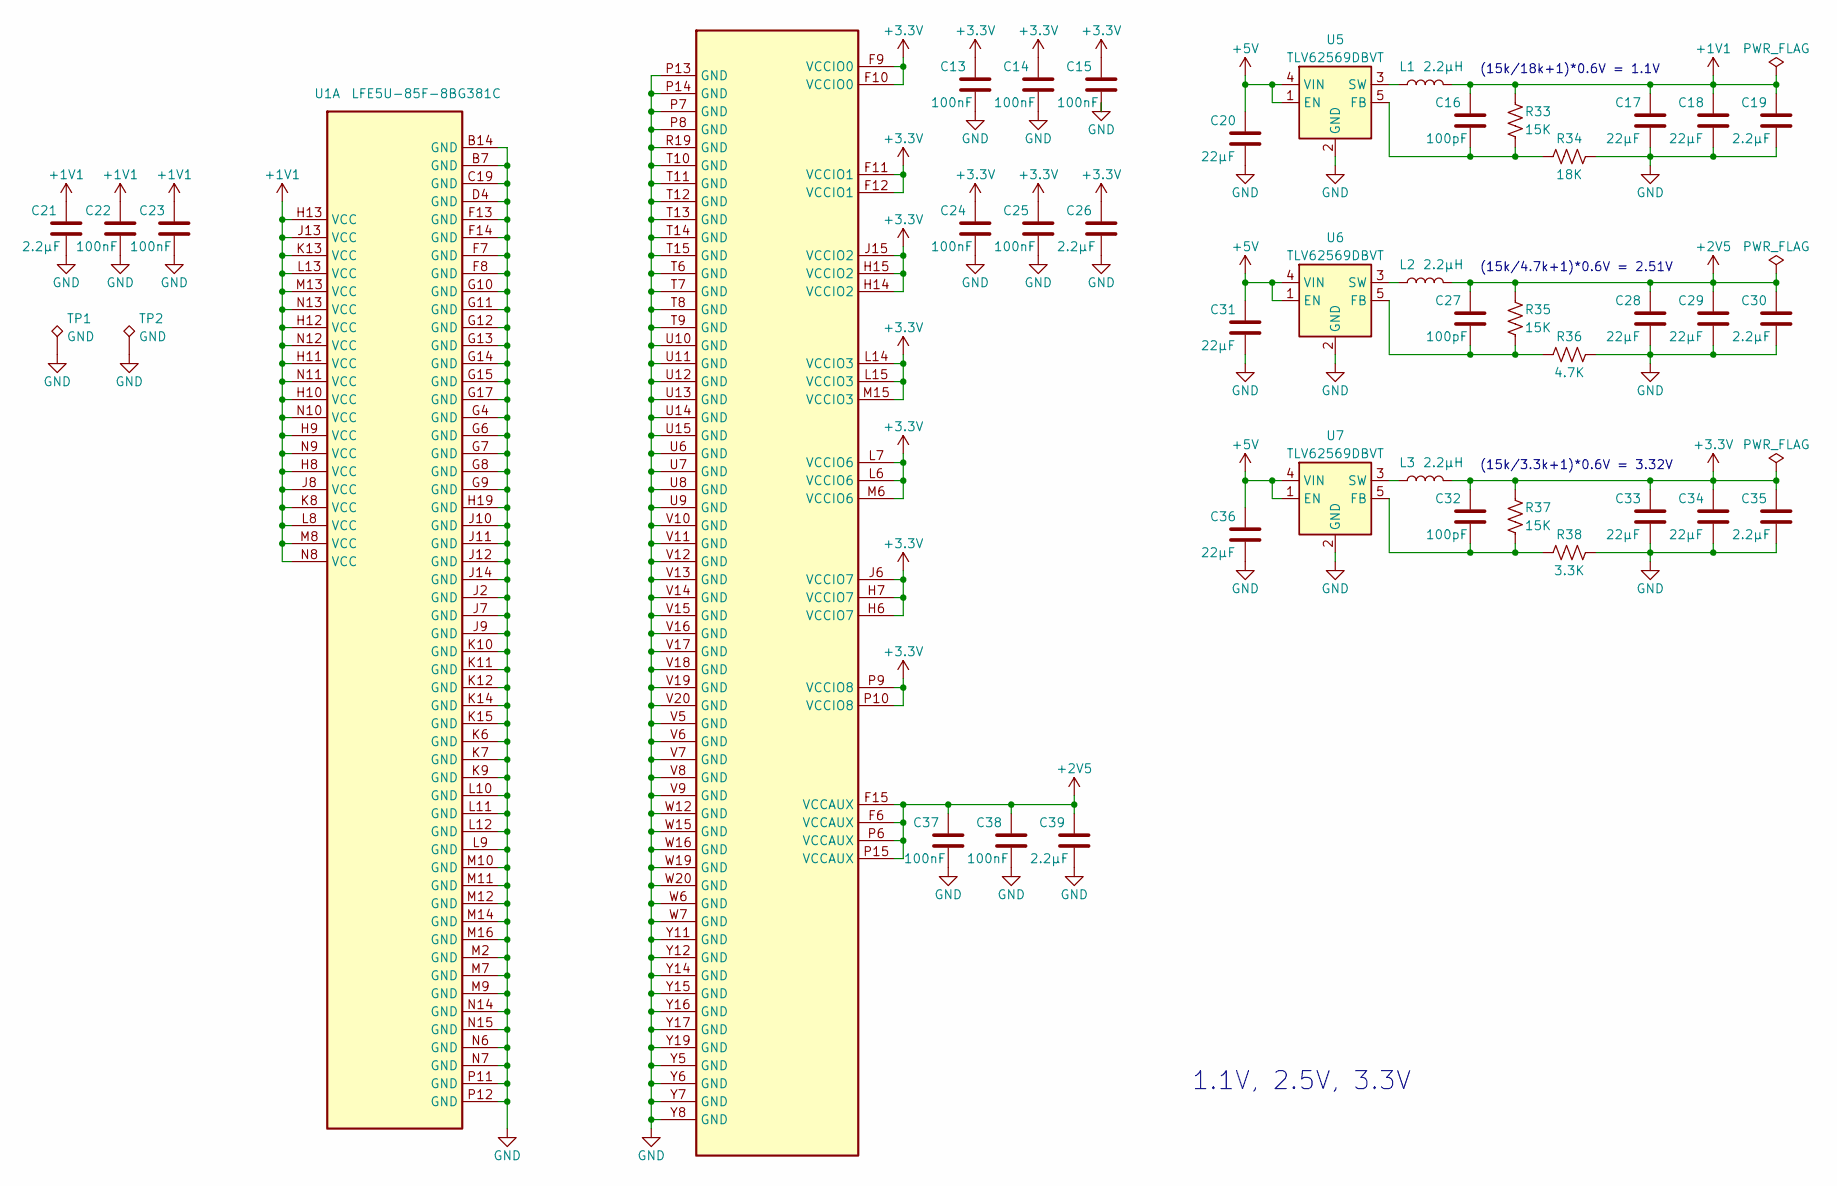
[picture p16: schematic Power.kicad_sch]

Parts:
C13, C14, C15, C22, C23, C24, C25, C37, C38: 100nF; C_0603_1608Metric; MPN CL10B104KB8NNWC
C16, C27, C32: 100pF; C_0603_1608Metric; MPN CL10C101FB81PNC
C17, C18, C20, C28, C29, C31, C33, C34, C36: 22µF; C_0603_1608Metric; MPN CL10A226MP8NUNE
C19, C21, C26, C30, C35, C39: 2.2µF; C_0603_1608Metric; MPN CL10B225KP8NNNC
L1, L2, L3: 2.2µH; L_1210_3225Metric; MPN DFE322512F-2R2M=P2
R33, R35, R37: 15K; R_0603_1608Metric; MPN ERJ-3EKF1502V
R34: 18K; R_0603_1608Metric; MPN ERJ-3EKF1802V
R36: 4.7K; R_0603_1608Metric; MPN ERJ-3EKF4701V
R38: 3.3K; R_0603_1608Metric; MPN ERJ-3EKF3301V
TP1, TP2: GND; TestPoint_THTPad_D2.0mm_Drill1.0mm; MPN 5001
U1: LFE5U-85F-8BG381C; BGA-381_pitch0.8mm_dia0.4mm; MPN LFE5U-85F-8BG381C
U5, U6, U7: TLV62569DBVT; SOT-23-5; MPN TLV62569DBVT

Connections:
+1V1: C16.1, C17.1, C18.1, C19.1, C21.1, C22.1, C23.1, L1.2, R33.1, U1.H8 (VCC), U1.H9 (VCC), U1.H10 (VCC), U1.H11 (VCC), U1.H12 (VCC), U1.H13 (VCC), U1.J8 (VCC), U1.J13 (VCC), U1.K8 (VCC), U1.K13 (VCC), U1.L8 (VCC), U1.L13 (VCC), U1.M8 (VCC), U1.M13 (VCC), U1.N8 (VCC), U1.N9 (VCC), U1.N10 (VCC), U1.N11 (VCC), U1.N12 (VCC), U1.N13 (VCC)
+2V5: C27.1, C28.1, C29.1, C30.1, C37.1, C38.1, C39.1, L2.2, R35.1, U1.F6 (VCCAUX), U1.F15 (VCCAUX), U1.P6 (VCCAUX), U1.P15 (VCCAUX)
+3.3V: C13.1, C14.1, C15.1, C24.1, C25.1, C26.1, C32.1, C33.1, C34.1, C35.1, L3.2, R37.1, U1.F9 (VCCIO0), U1.F10 (VCCIO0), U1.F11 (VCCIO1), U1.F12 (VCCIO1), U1.H6 (VCCIO7), U1.H7 (VCCIO7), U1.H14 (VCCIO2), U1.H15 (VCCIO2), U1.J6 (VCCIO7), U1.J15 (VCCIO2), U1.L6 (VCCIO6), U1.L7 (VCCIO6), U1.L14 (VCCIO3), U1.L15 (VCCIO3), U1.M6 (VCCIO6), U1.M15 (VCCIO3), U1.P9 (VCCIO8), U1.P10 (VCCIO8); also elsewhere on the board
+5V: C20.1, C31.1, C36.1, U5.1 (EN), U5.4 (VIN), U6.1 (EN), U6.4 (VIN), U7.1 (EN), U7.4 (VIN); also elsewhere on the board
GND: C13.2, C14.2, C15.2, C17.2, C18.2, C19.2, C20.2, C21.2, C22.2, C23.2, C24.2, C25.2, C26.2, C28.2, C29.2, C30.2, C31.2, C33.2, C34.2, C35.2, C36.2, C37.2, C38.2, C39.2, R34.2, R36.2, R38.2, TP1.1, TP2.1, U1.B7 (GND), U1.B14 (GND), U1.C19 (GND), U1.D4 (GND), U1.F7 (GND), U1.F8 (GND), U1.F13 (GND), U1.F14 (GND), U1.G4 (GND), U1.G6 (GND), U1.G7 (GND), U1.G8 (GND), U1.G9 (GND), U1.G10 (GND), U1.G11 (GND), U1.G12 (GND), U1.G13 (GND), U1.G14 (GND), U1.G15 (GND), U1.G17 (GND), U1.H19 (GND), U1.J2 (GND), U1.J7 (GND), U1.J9 (GND), U1.J10 (GND), U1.J11 (GND), U1.J12 (GND), U1.J14 (GND), U1.K6 (GND), U1.K7 (GND), U1.K9 (GND), U1.K10 (GND), U1.K11 (GND), U1.K12 (GND), U1.K14 (GND), U1.K15 (GND), U1.L9 (GND), U1.L10 (GND), U1.L11 (GND), U1.L12 (GND), U1.M2 (GND), U1.M7 (GND), U1.M9 (GND), U1.M10 (GND), U1.M11 (GND), U1.M12 (GND), U1.M14 (GND), U1.M16 (GND), U1.N6 (GND), U1.N7 (GND), U1.N14 (GND), U1.N15 (GND), U1.P7 (GND), U1.P8 (GND), U1.P11 (GND), U1.P12 (GND), U1.P13 (GND), U1.P14 (GND), U1.R19 (GND), U1.T6 (GND), U1.T7 (GND), U1.T8 (GND), U1.T9 (GND), U1.T10 (GND), U1.T11 (GND), U1.T12 (GND), U1.T13 (GND), U1.T14 (GND), U1.T15 (GND), U1.U6 (GND), U1.U7 (GND), U1.U8 (GND), U1.U9 (GND), U1.U10 (GND), U1.U11 (GND), U1.U12 (GND), U1.U13 (GND), U1.U14 (GND), U1.U15 (GND), U1.V5 (GND), U1.V6 (GND), U1.V7 (GND), U1.V8 (GND), U1.V9 (GND), U1.V10 (GND), U1.V11 (GND), U1.V12 (GND), U1.V13 (GND), U1.V14 (GND), U1.V15 (GND), U1.V16 (GND), U1.V17 (GND), U1.V18 (GND), U1.V19 (GND), U1.V20 (GND), U1.W6 (GND), U1.W7 (GND), U1.W12 (GND), U1.W15 (GND), U1.W16 (GND), U1.W19 (GND), U1.W20 (GND), U1.Y5 (GND), U1.Y6 (GND), U1.Y7 (GND), U1.Y8 (GND), U1.Y11 (GND), U1.Y12 (GND), U1.Y14 (GND), U1.Y15 (GND), U1.Y16 (GND), U1.Y17 (GND), U1.Y19 (GND), U5.2 (GND), U6.2 (GND), U7.2 (GND); also elsewhere on the board
unnamed: C16.2, R33.2, R34.1, U5.5 (FB)
unnamed: L1.1, U5.3 (SW)
unnamed: C27.2, R35.2, R36.1, U6.5 (FB)
unnamed: L2.1, U6.3 (SW)
unnamed: C32.2, R37.2, R38.1, U7.5 (FB)
unnamed: L3.1, U7.3 (SW)

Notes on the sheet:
(15k/3.3k+1)*0.6V = 3.32V
(15k/18k+1)*0.6V = 1.1V
(15k/4.7k+1)*0.6V = 2.51V
1.1V, 2.5V, 3.3V

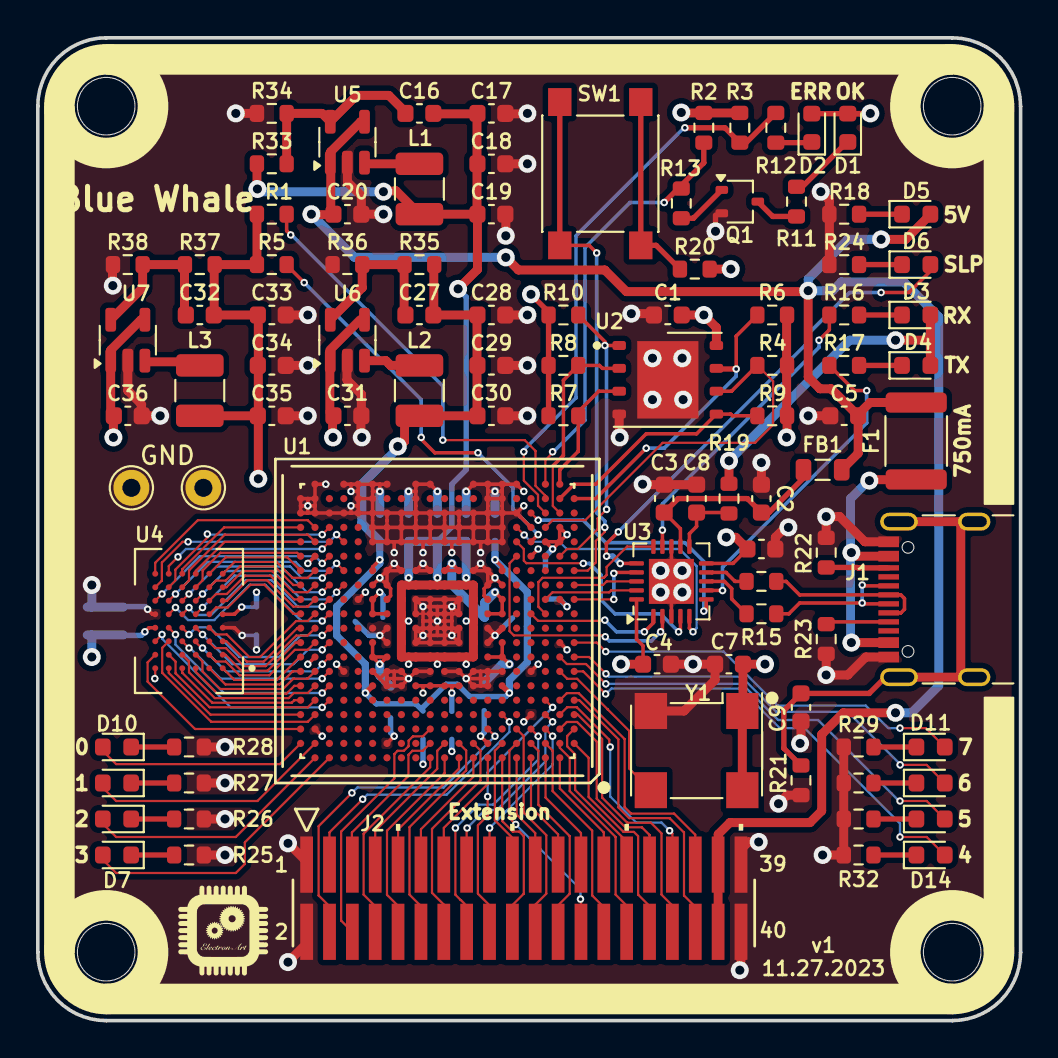
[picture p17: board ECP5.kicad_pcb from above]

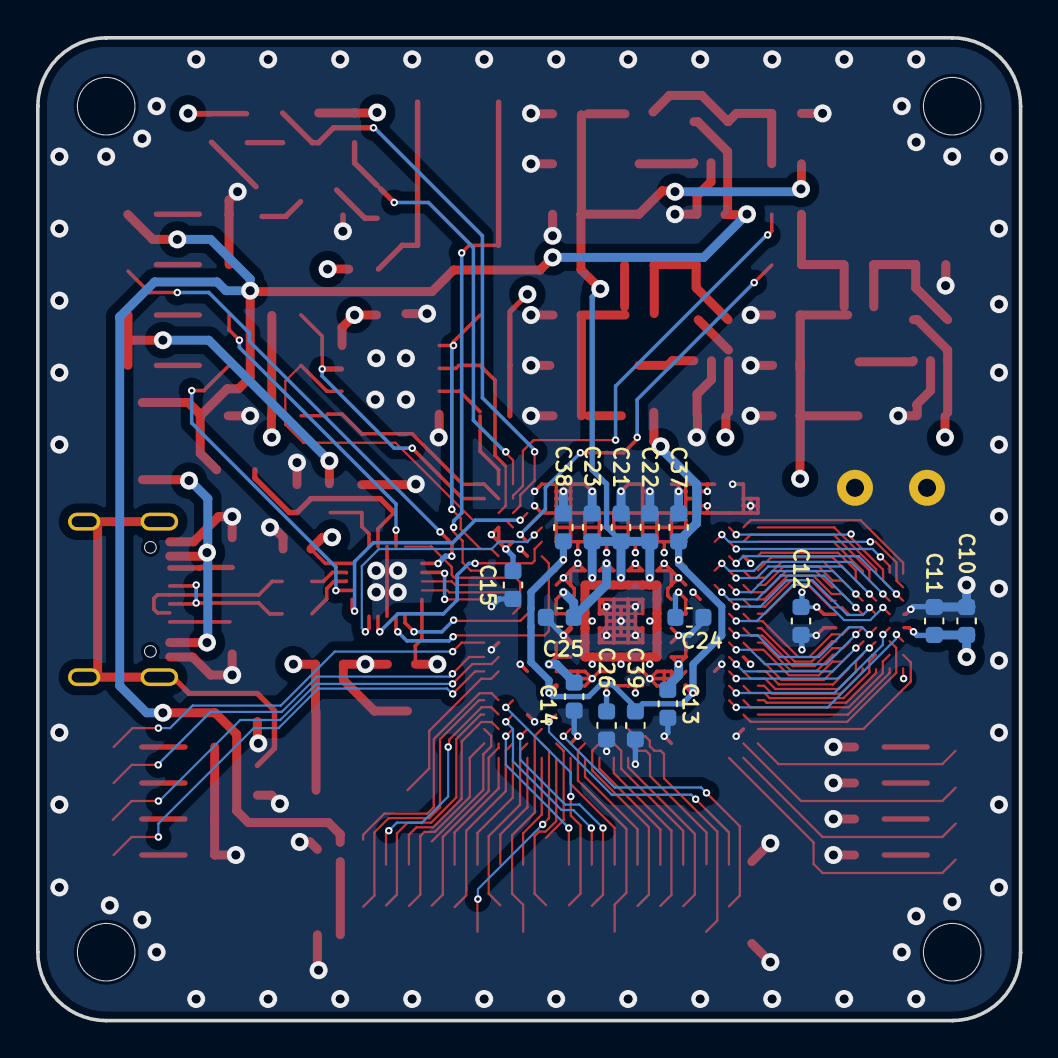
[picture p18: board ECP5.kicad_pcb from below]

Board: 4 copper layers, 54.6 x 54.6 mm, 114 parts (15 on the bottom side), 148 nets.

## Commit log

2024-01-15 FPGA first commit
    Added Kicad project file, schematics. PCB, symbols, footprints, 3dmodels.
    [0ZCG-0_70mm.STEP, CRYSTAL_7050-4.step, ECP5.kicad_pcb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]
2024-07-06 Switched to project library
    [ECP5.kicad_pcb, ECP5.kicad_sch, Flash_JTAG.kicad_sch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]
2024-09-06 Changed the name of the project path to ECP5_BGA381_RISCV
    [ECP5.kicad_pcb, Flash_JTAG.kicad_sch, Power.kicad_sch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]

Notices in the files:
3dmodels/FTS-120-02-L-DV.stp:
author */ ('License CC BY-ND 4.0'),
